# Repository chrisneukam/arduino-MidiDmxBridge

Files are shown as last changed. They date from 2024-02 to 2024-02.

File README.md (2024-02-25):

# Arduino Project: MIDI-DMX Bridge






The `MIDI-DMX Bridge` is an Arduino-based hardware and software solution that converts MIDI Continuous Controller signals to DMX commands. The project consists of a hardware schematic and PCB designed using KiCad, an Arduino sketch, and an Arduino library. It can be used to control DMX fixtures such as lights, fog machines, and more.

## Lightning Fixture Compatibility

The `MIDI-DMX Bridge` Arduino project is designed to seamlessly integrate with the lighting fixtures *Stairville CLB4 RGB Compact LED Bar 4* and two *Stairville LED Flood Panel 150*. Here's how the bridge supports these fixtures:

1. **Stairville CLB4 RGB Compact LED Bar 4**:
    - This LED bar operates in the 14-channel DMX mode, the start address 1.
    - Each of its four individual LED spots can be controlled independently using the MIDI-DMX Bridge.
    - Adjust colors, intensity, and effects with precision.
    - Perfect for creating dynamic lighting displays in various settings.

2. **Stairville LED Flood Panel 150**:
    - The LED Flood Panel operates in the 4-channel DMX mode, the start addresses are 15 and 19.
    - Use the MIDI-DMX Bridge to orchestrate its 150 LEDs for wide-area illumination.
    - Whether it’s stage lighting, architectural displays, or events, this panel delivers impressive results.

Remember to consult the user manuals for both fixtures to configure the MIDI-DMX Bridge effectively. Enjoy your creative lighting setups! 🌟

## Hardware Schematic

The hardware schematic for this project was designed using KiCad. The schematic includes the following components:

- **MIDI Input**: This component receives MIDI Continuous Controller signals on a defined MIDI channel from an external device.
- **Arduino Board**: This component processes the incoming MIDI signals and generates DMX commands.
- **DMX Output**: This component sends DMX commands to an external DMX device.
- **Potentiometer**: This component allows the user to adjust the intensity of the DMX signal.
- **Hardware Switch**: This component allows the user to select either a predefined DMX scene or the MIDI controlled dynamic scene.

Hardware Schematic

The DMX circuit is based on the `DMX shield` from Matthias Hertel, see [DMX Shield for Arduino with isolation](https://www.mathertel.de/Arduino/DMXShield.aspx).

## PCB Design of the MIDI-DMX Bridge

The hardware design focuses on efficiency and space-saving. The compact printed circuit board (PCB) houses all essential components, including the Arduino ProMini microcontroller, MIDI interface, and DMX driver.

The PCB has the following features:

- A MIDI input jack that accepts standard 5-pin DIN connectors
- A MIDI through jack that accepts standard 5-pin DIN connectors
- A DMX output jack that supports both 3-pin XLR connectors
- A power jack that provides 9V DC power
- A Switch that selects between two DMX modes: static and dynamic scene
- A potentiometer that adjusts the DMX signal strength

The PCB layout and the circuit diagram as a 3D simulation, before and after final assembly, are shown below:

PCB 3D layout

PCB layout
PCB layout after assembly

The PCB can be ordered from any PCB manufacturer that supports the KiCad format. Alternatively, the [Interactive BOM](./kicad/bom/ibom.html) tool can help with the assembly of the PCB.

The PCB shown was manufactured by [JLCPCB](https://jlcpcb.com/), the production data can be found in [kicad\production](./kicad/production) as a reference.

## Arduino Sketch

The Arduino sketch for this project is responsible for processing the incoming MIDI signals and generating DMX commands. The sketch uses its own implementation to receive MIDI signals and the [DMXSerial Library](https://github.com/mathertel/DMXSerial) to send DMX commands.

```c++
#include <DMXSerial.h>
#include <MidiDmxBridge.h>

static void onDmxChange(const uint8_t channel, const uint8_t value) {
  DMXSerial.write(channel, value);
}

static SerialReaderDefault reader;
static MidiDmxBridge MDXBridge(kMidiChannel, onDmxChange, reader);

void setup() {
  DMXSerial.init(DMXController);
  MDXBridge.begin();
}

void loop() {
  MDXBridge.setAttenuation(analogRead(kSensorPin));
  MDXBridge.listen();
}
```

For the complete Arduino sketch, please refer to [arduino-MidiDmxBridge.ino](./src/arduino-MidiDmxBridge/arduino-MidiDmxBridge.ino).

## Arduino Library

The Arduino library for this project is a custom library that provides additional functionality for processing MIDI signals and generating DMX commands. It is also available as [MidiDmxBridge](https://reference.arduino.cc/reference/en/libraries/mididmxbridge/) via the [Arduino Library manager](https://docs.arduino.cc/software/ide-v1/tutorials/installing-libraries/).
The library includes the following functions:

- `void begin()`: This function processes initializes the library.
- `void setStaticScene(const DmxRgbChannels& channels, const DmxRgb& rgb)`: This function defines the DMX static scene
- `void setAttenuation(const uint16_t attenuation)`: This function switches to the MIDI controlled dynamic scene.
- `void switchToDynamicScene()`: This function sets the attenuation of the generated DMX signal.
- `void switchToStaticScene()`: This function switches to the predefined static scene.
- `void listen()`: This function listens on the serial interface for the next MIDI CC value and updates the DMX state.

```c++
class MidiDmxBridge {
public:
  MidiDmxBridge(const uint8_t channel, DmxOnChangeCallback callback, ISerialReader& serial);
  void begin();
  void setStaticScene(const DmxRgbChannels& channels, const DmxRgb& rgb);
  void setAttenuation(const uint16_t attenuation);
  void switchToDynamicScene();
  void switchToStaticScene();
  void listen();
};
```

For the complete API, please refer to [MidiDmxBridge.h](./src/arduino-library/MidiDmxBridge/src/MidiDmxBridge.h).

### C++ Library development

The Arduino library is developed in C++ and uses CMake for configuration. The library is tested using gtest and documented using Doxygen.

```shell
cmake -S ./src/arduino-library/ -B ./build
cmake --build ./build
ctest --test-dir ./build/
```

On Linux OS code coverage using lcov and gcov is available:

```shell
cmake -DENABLE_COVERAGE=ON -S ./src/arduino-library/ -B ./build
cmake --build ./build
ctest --test-dir ./build/
cmake --build ./build --target coverage
```

The software documentation can then be accessed at [./build/html/index.html](./build/html/index.html), the code coverage results at [./build/coverage/index.html](./build/coverage/index.html).

## How to Run Codespell

To run [codespell](https://github.com/codespell-project/codespell), you need to have Python 3 installed on your system. You can install Python 3 from the official website: https://www.python.org/downloads/.

Once you have Python 3 installed, you can install [codespell](https://github.com/codespell-project/codespell) using pip, the Python package manager. Open a terminal or command prompt and type the following command:

```bash
pip install codespell
```

This will install [codespell](https://github.com/codespell-project/codespell) and all its dependencies.

To run [codespell](https://github.com/codespell-project/codespell), navigate to the root directory of your project in the terminal or command prompt and type the following command:

```bash
codespell
```

This will run [codespell](https://github.com/codespell-project/codespell) on all the files in the current directory and its subdirectories. [codespell](https://github.com/codespell-project/codespell) will check for common misspellings and suggest corrections. You can use the `-w` option to write the changes directly to the files.

```bash
codespell -w
```

For more information on how to use [codespell](https://github.com/codespell-project/codespell), including a list of all the available options, please refer to the official documentation: https://github.com/codespell-project/codespell#usage.

## Generating a Source Code Release Package with CPack

CPack is a powerful tool that allows to create binary installers and source packages. To generate a source code release package, use the following commands:

```bash
cd ./build
cpack --config CPackSourceConfig.cmake
```

This will create a source package in the CMake build directory.

## Conclusion

This project provides a simple and effective solution for converting MIDI Continuous Controller signals to DMX commands. The hardware schematic, Arduino sketch, and Arduino library can be easily modified to suit your specific needs. If you have any questions or comments about this project, please feel free to contact me.

## License

This library and the PCB design are released under the Apache V2.0 License. See [LICENSE](./LICENSE) for more information.

Please let me know if you have any questions or feedback. I'm happy to help! 😊🎵

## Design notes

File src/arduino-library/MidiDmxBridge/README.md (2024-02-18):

# MIDI-DMX Bridge Arduino library





This library allows you to translate MIDI Continuous Controller signals received at a user-defined channel into DMX commands. The library is compatible with Arduino boards and can be used to control DMX fixtures such as lights, fog machines, and more.

## Installation

1. Download the latest version of the library from the [GitHub repository](https://github.com/chrisneukam/MidiDmxBridge).
2. Extract the ZIP file and copy the folder to your Arduino libraries directory.
3. Restart the Arduino IDE.

## Usage

1. Include the library in your Arduino sketch by adding the following line at the beginning of your code:

```cpp
#include <MidiDmxBridge.h>
```

2. Define the callback method `mididmxbridge::dmx::DmxOnChangeCallback` with the signature `(const uint8_t, const uint8_t)`, which receives the DMX updates:

```cpp
static void onDmxChange(const uint8_t channel, const uint8_t value) {
}
```

3. Instantiate a `MidiDmxBridge` and `mididmxbridge::ISerialReader` object in you sketch:

```cpp
static SerialReaderDefault reader;
static MidiDmxBridge MDXBridge(kMidiChannel, onDmxChange, reader);
```

4. Initialize the library by calling the `begin()` function in the `setup()` function of your sketch:

```cpp
void setup() {
  MDXBridge.begin();
}
```

5. In the `loop()` function of your sketch, call the `listen()` function to listen to incoming MIDI messages and translate them into DMX commands:

```cpp
void loop() {
  MDXBridge.listen();
}
```

6. Use the `setAttenuation()` function to adjust the intensity of the dynamic and static scenes:

```cpp
MDXBridge.setAttenuation(512);
```

7. Use the `switchToDynamicScene()` function to switch to the dynamic scene:

```cpp
MDXBridge.switchToDynamicScene();
```

8. Use the `switchToStaticScene()` function to switch to the static scene:

```cpp
MDXBridge.switchToStaticScene();
```

## Example

Here's an example sketch that uses the library to control a DMX light fixture listening on MIDI channel 1 and using pins 3 and 4 for MIDI IO:

```cpp
#include <MidiDmxBridge.h>

static void onDmxChange(const uint8_t channel, const uint8_t value) {}

static SerialReaderDefault reader(3, 4);
static MidiDmxBridge MDXBridge(1, onDmxChange, reader);

void setup() {
  MIDI_DMX.begin();
  MDXBridge.setStaticScene();

}

void loop() {
  MDXBridge.setAttenuation(512);
  MDXBridge.listen();
  MDXBridge.switchToStaticScene();
  delay(1000);
  MDXBridge.switchToDynamicScene();
  delay(1000);
}
```

## License

This library is released under the Apache V2.0 License. See [LICENSE](./LICENSE) for more information.

Please let me know if you have any questions or feedback. I'm happy to help! 😊

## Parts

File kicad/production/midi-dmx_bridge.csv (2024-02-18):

Comment | Designator | Footprint
10k | R4 | R_1206_3216Metric
6N137 | OC2,OC1 | SOP-8-2.54mm
220 | R2,R3,R1 | R_1206_3216Metric
100n | C6,C2,C4,C1,C5,C3 | C_1206_3216Metric
100k | R5 | R_1206_3216Metric
MBR0520 | D3 | D_SOD-123
1N914 | D2,D1 | D_SOD-123
MAX485E | IC1 | SOIC-8_3.9x4.9mm_P1.27mm
270 | R6 | R_1206_3216Metric
4.7k | R8 | R_1206_3216Metric
470 | R7 | R_1206_3216Metric
120 | R9 | R_1206_3216Metric

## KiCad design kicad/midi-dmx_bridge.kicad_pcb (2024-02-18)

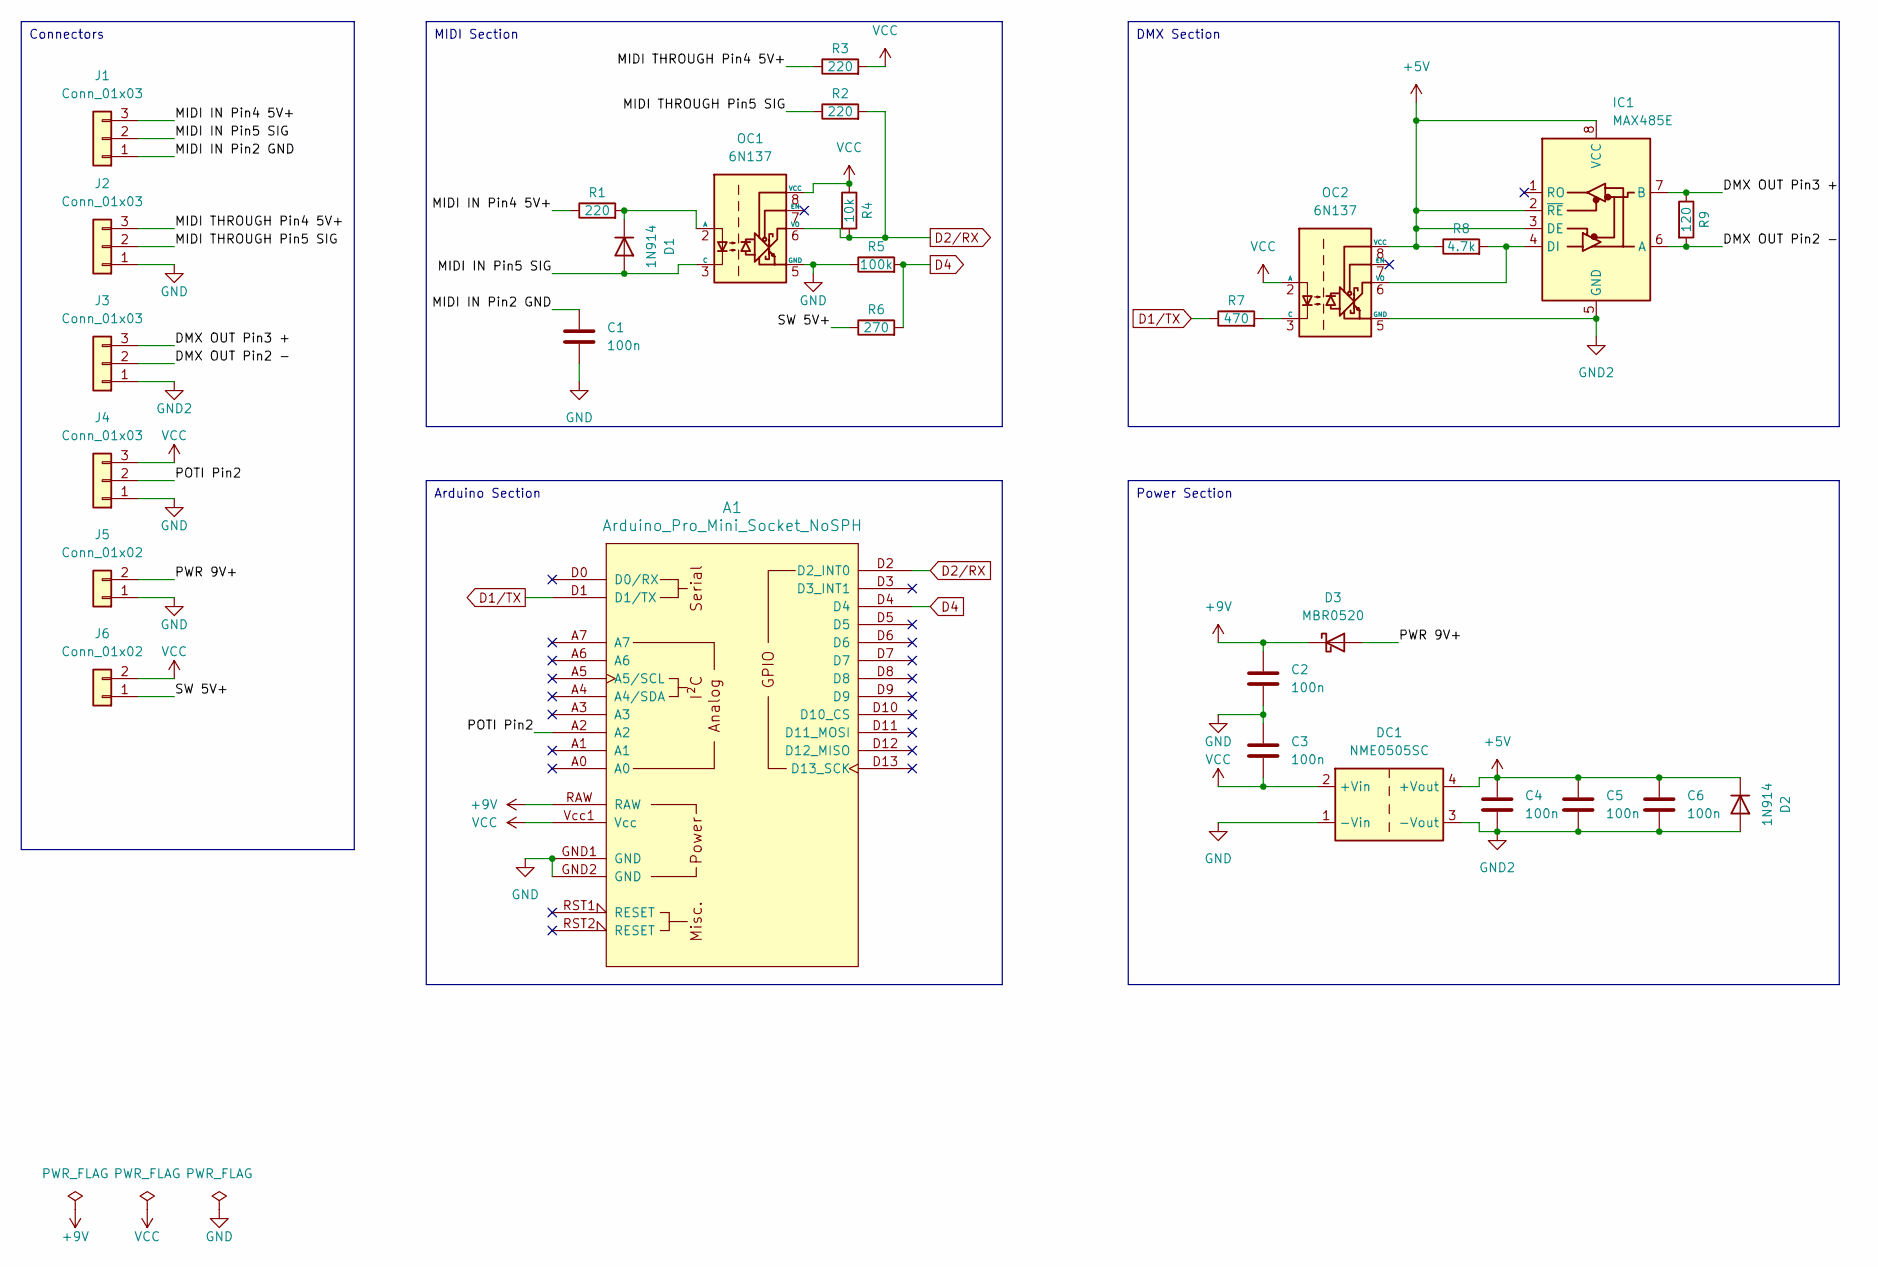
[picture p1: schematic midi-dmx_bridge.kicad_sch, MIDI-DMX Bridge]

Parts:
A1: Arduino_Pro_Mini_Socket_NoSPH
C1, C2, C3, C4, C5, C6: 100n; C_1206_3216Metric
D1, D2: 1N914; D_SOD-123
D3: MBR0520; D_SOD-123
DC1: NME0505SC; Converter_DCDC_Murata_MEE1SxxxxSC_THT
IC1: MAX485E; SOIC-8_3.9x4.9mm_P1.27mm
J1, J2, J3, J4: Conn_01x03; Molex_KK-254_AE-6410-03A_1x03_P2.54mm_Vertical
J5, J6: Conn_01x02; Molex_KK-254_AE-6410-02A_1x02_P2.54mm_Vertical
OC1, OC2: 6N137; SMDIP-8_W9.53mm
R1, R2, R3: 220; R_1206_3216Metric
R4: 10k; R_1206_3216Metric
R5: 100k; R_1206_3216Metric
R6: 270; R_1206_3216Metric
R7: 470; R_1206_3216Metric
R8: 4.7k; R_1206_3216Metric
R9: 120; R_1206_3216Metric

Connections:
+5V: C4.1, C5.1, C6.1, D2.1 (K), DC1.4 (+Vout), IC1.2 (~RE), IC1.3 (DE), IC1.8 (VCC), OC2.8 (VCC), R8.1
+9V: A1.RAW, C2.1, D3.1 (K)
/DMX OUT Pin2 -: IC1.6 (A), J3.2, R9.2
/DMX OUT Pin3 +: IC1.7 (B), J3.3, R9.1
/MIDI IN Pin2 GND: C1.1, J1.1
/MIDI IN Pin4 5V+: J1.3, R1.1
/MIDI IN Pin5 SIG: D1.2 (A), J1.2, OC1.3 (C)
/MIDI THROUGH Pin4 5V+: J2.3, R3.1
/MIDI THROUGH Pin5 SIG: J2.2, R2.1
/POTI Pin2: A1.A2, J4.2
/PWR 9V+: D3.2 (A), J5.2
/SW 5V+: J6.1, R6.1
D1/TX: A1.D1 (D1/TX), R7.1
D2/RX: A1.D2 (D2_INT0), OC1.6 (VO), R2.2, R4.2
D4: A1.D4, R5.2, R6.2
GND: A1.GND1 (GND), A1.GND2 (GND), C1.2, C2.2, C3.1, DC1.1 (-Vin), J2.1, J4.1, J5.1, OC1.5 (GND), R5.1
GND2: C4.2, C5.2, C6.2, D2.2 (A), DC1.3 (-Vout), IC1.5 (GND), J3.1, OC2.5 (GND)
unnamed: D1.1 (K), OC1.2 (A), R1.2
unnamed: IC1.4 (DI), OC2.6 (VO), R8.2
unnamed: OC2.3 (C), R7.2
VCC: A1.Vcc1 (Vcc), C3.2, DC1.2 (+Vin), J4.3, J6.2, OC1.8 (VCC), OC2.2 (A), R3.2, R4.1

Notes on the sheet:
DMX Section
Arduino Section
MIDI Section
Power Section
Connectors

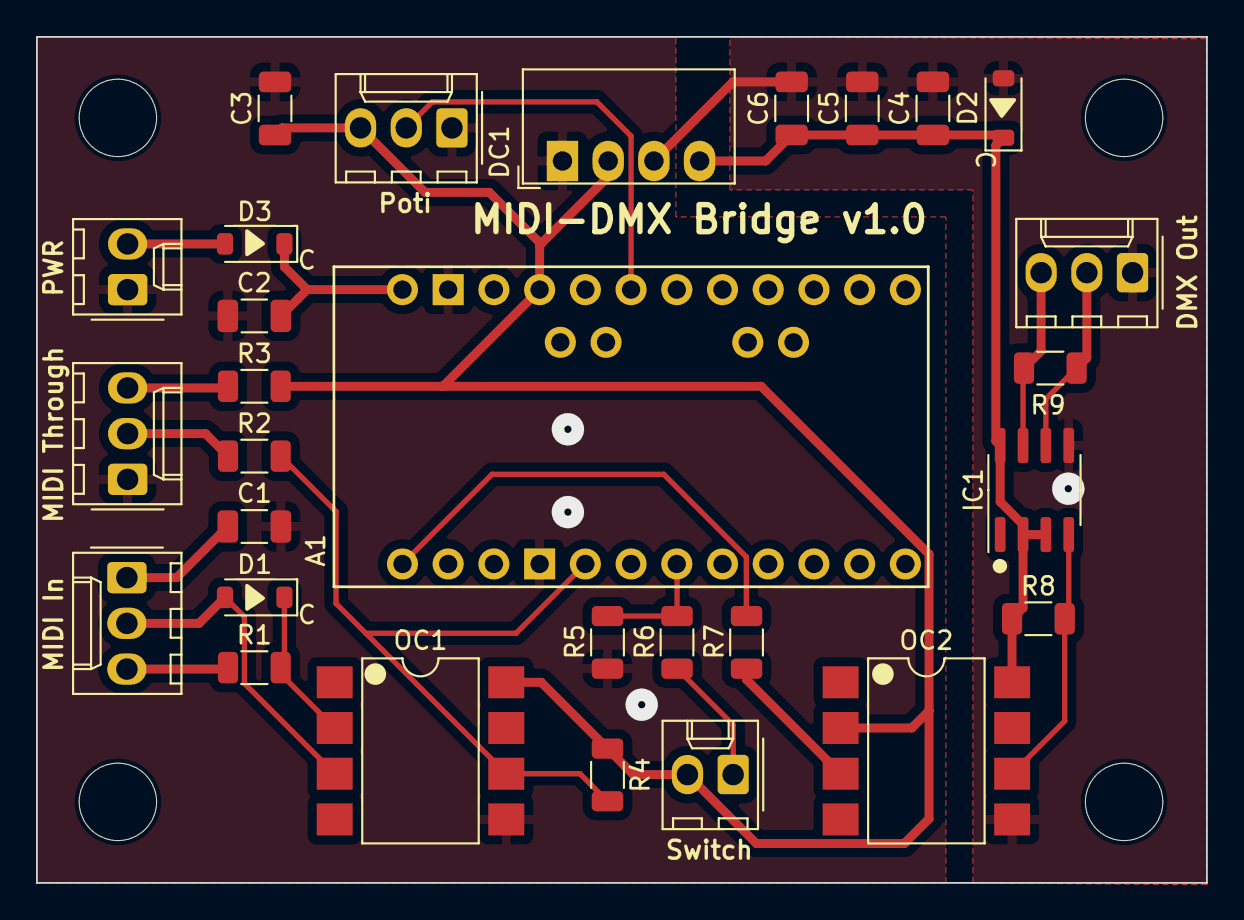
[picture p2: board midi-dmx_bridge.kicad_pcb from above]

Board: 2 copper layers, 65.0 x 47.0 mm, 29 parts (0 on the bottom side), 21 nets.

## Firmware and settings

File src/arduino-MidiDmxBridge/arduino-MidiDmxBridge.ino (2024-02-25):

/**
 * @file arduino-MidiDmxBridge.ino
 * @author Christian Neukam
 * @brief Arduino program of the MIDI-DMX Bridge project.
 * @version 1.0
 * @date 2023-12-12
 *
 * @copyright Copyright 2023 Christian Neukam. All rights reserved.
 *
 * Licensed under the Apache License, Version 2.0 (the "License");
 * you may not use this file except in compliance with the License.
 * You may obtain a copy of the License at
 *
 *     http://www.apache.org/licenses/LICENSE-2.0
 *
 * Unless required by applicable law or agreed to in writing, software
 * distributed under the License is distributed on an "AS IS" BASIS,
 * WITHOUT WARRANTIES OR CONDITIONS OF ANY KIND, either express or implied.
 * See the License for the specific language governing permissions and
 * limitations under the License.
 */
#include <DMXSerial.h>
#include <MidiDmxBridge.h>

#if defined(USBCON)
#define USBSerial /**< Micro and other USB boards use Serial for tracing. */
#endif

/***************************************************************/
/* configuration - Arduino Pro / Pro Mini only !!              */
/***************************************************************/
#define kMidiChannel 9 /**< the MIDI channel to listen to */
#define kSensorPin A2  /**< the input pin for the potentiometer */
#define kMidiRxPin 2   /**< the input pin for the MIDI data */
#define kMidiTxPin 3   /**< the output pin for the MIDI data (not used) */
#define kButtonPin 4   /**< the input pin for the hardware switch */

/**
 * @brief Implementation of the callback mididmxbridge::dmx::DmxOnChangeCallback.
 *
 * This callback is always called as soon as a new DMX date is generated from a
 * MIDI CC signal.
 *
 * @param[in] channel the DMX channel in the range [1, 255]
 * @param[in] value the DMX value in the range [1, 255]
 */
static void onDmxChange(const uint8_t channel, const uint8_t value) {
  DMXSerial.write(channel, value);

#ifdef USBSerial
  String msg = "DMX channel / value: [" + String(channel) + " | " + String(value) + "]";
  Serial.println(msg);
#endif
}

static SerialReaderDefault reader(kMidiRxPin, kMidiTxPin); /**< the serial reader receiving MIDI */
static MidiDmxBridge MDXBridge(kMidiChannel, onDmxChange, reader); /**< the MidiDmxBridge object */

/**
 * @brief Setup the Arduino board.
 *
 * The setup routine is called up once when the Arduino board is started. The
 * setup routine is called up once when the Arduino board is started. This is
 * where the serial interfaces are initialized and the pin modes are set.
 *
 * The static scene is calibrated to warm white with the color code for 5100K
 * (rgb = [255, 248, 167] = [ff, f8, a7]).
 */
void setup() {
  pinMode(kButtonPin, INPUT);
  pinMode(LED_BUILTIN, OUTPUT);

  uint8_t r[6] = {1, 4, 7, 10, 16, 20};  // DMX channels of the red LEDs
  uint8_t g[6] = {2, 5, 8, 11, 17, 21};  // DMX channels of the green LEDs
  uint8_t b[6] = {3, 6, 9, 12, 18, 22};  // DMX channels of the blue LEDs
  uint8_t d[3] = {14, 15, 19};           // DMX channels of the dimmers

#ifdef USBSerial
  Serial.begin(9600);  // print info on the serial monitor, USB only
#endif
  DMXSerial.init(DMXController);
  DMXSerial.maxChannel(128);
  MDXBridge.begin();
  MDXBridge.setStaticScene({{6, r}, {6, g}, {6, b}}, {0xff, 0xf8, 0xa7});
  MDXBridge.setStaticScene({{3, d}, {}, {}}, {0xff, 0x00, 0x00});
}

/**
 * @brief The main processing loop.
 *
 */
void loop() {
  const int state = digitalRead(kButtonPin);

  if (HIGH == state) {
    MDXBridge.switchToStaticScene();
  } else {
    MDXBridge.switchToDynamicScene();
  }
  digitalWrite(LED_BUILTIN, state);

  MDXBridge.setAttenuation(analogRead(kSensorPin));
  MDXBridge.listen();
}

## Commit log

2024-02-18 feat: MIDI-DMX Bridge (#1)
    This is the first fully functional version of the MIDI-DMX Bridge
    Arduino project. It consists of the MIDI-DMX Bridge schematic created
    in KiCad, the Arduino library developed in C++ and the Arduino sketch
    for the Arduino Pro Mini.
    [midi-dmx_bridge-B_Cu.gbr, midi-dmx_bridge-B_Mask.gbr, midi-dmx_bridge-B_Paste.gbr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]
2024-02-25 feat: Dimmer Support
    In addition to the RGB channels, this feature also takes into account the dimmers of the lighting fixtures.
    Full support of Stairville CLB4 RGB Compact LED Bar 4 and Stairville LED Flood Panel 150.
    [arduino-MidiDmxBridge.ino]

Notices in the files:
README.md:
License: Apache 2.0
